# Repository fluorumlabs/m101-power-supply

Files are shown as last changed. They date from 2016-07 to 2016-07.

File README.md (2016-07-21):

# M101 Power Supply #

	Current version: M101 rev.D
	State: Tested
	Build Difficulty: Medium

Basic switched-mode power supply module for [FluorumLabs SonicTrain](https://github.com/fluorumlabs/sonictrain) modular sound processing system.

![Assembled Module]()

## Features ##

 * Up to 15W output power (500mA on positive and negative rails); depends on the DC-DC converter used.
 * 2.0 mm center pin DC power jack (center pin positive).
 * Reverse polarity protection.
 * Supports all ±15V dual output DC-DC converters in industry standard through-hole 1x1 footprint, with optional positive or negative remote ON/OFF control.
 * Optional ON/OFF switch.
 * Automatic optical switch provides power to the rest of the system only after the last (audio output) module is connected, guaranteeing the both rails will be powered simultaneously.
 * MOSFET current limiter for limiting in-rush current on system power-up.

![Plain PCB]()

![Populated PCB]()

## Schematics and PCB ##

 * [Schematics (PDF)](eagle/m101-power-supply.pdf)
 * [Schematics (Eagle 7)](eagle/m101-power-supply.sch)
 * [PCB (Eagle 7)](eagle/m101-power-supply.brd)

## Ordering and Building Notes ##

Populating the PCB should be relatively straightforward. Some notes:

 * Always check the correct orientation of components:
   * Diodes: square pad on PCB marks **anode**.
   * Electrolytic capacitors: square pad on PCB marks **positive** lead (the long lead).
   * IC, optocoupler: square pad on PCB marks **pin 1** of package.
   * LED: square pad on PCB marks **anode** of the **first diode** (the second longest lead).
   * MOSFET: square pads on PCB mark MOSFET **drain** (two connected pins).

 * The switch orientation depends on remote ON/OFF function of selected DC-DC converter:
   * Positive remote ON/OFF: mount switch in POS position.
   * Negative remove ON/OFF: mount switch in NEG position.

 * If you want to omit switch and selected DC-DC converter has a negative remote ON/OFF function, connect two solder pads beneath the switch on the bottom side of the board.

 * If selected DC-DC converter doesn't have remote ON/OFF feature, leave the switch out.

## Bill of Materials (Assembly M101 rev.D) ##

Qty | RefDes | Component | Notes
--- | ------ | --------- | -----
1 | PCB1 | PCB M101 rev.D |
2 | C1, C3 | Capacitors Aluminium 33u/50V 8x7mm | Low profile
1 | C2 | Capacitors Aluminium 10u/35V 5x7mm | Low profile
2 | C4, C7 | Capacitors Ceramic 100n Radial | Lead space 5mm
2 | C5, C6 | Capacitors Aluminium Organic 39u/35V 8x7mm | Low profile
2 | C8, C9 | Capacitors Film 100n 2.5x7.2x6mm
2 | C10, C11 | Capacitors Aluminium 1u/50V 4x7mm | Low profile
2 | C12, C13 | Capacitors Film 22n 2.5x7.2x6mm
1 | DA1 | IC Logic NE555 DIP-8 |
1 | HL1 | LED 2x5x7mm Diffused Red/Blue (Common Cathode) |
1 | L1 | Ferrite Bead Axial |
1 | R1 | Resistors 22k 1% 0.25W |
1 | R2 | Resistors Array 4x100k SIP-5 |
1 | R3 | Resistors 10k 1% 0.25W |
3 | R4, R6, R7 | Resistors 100k 1% 0.25W |
3 | R5, R8, R9 | Resistors 1k5 1% 0.25W |
2 | R10, R11 | Resistors 220k 1% 0.125W |
2 | R12, R13 | Resistors 100R 1% 0.25W |
1 | SA1 | Switches Slide MHS122K | Optional, leave out if no switch is needed
2 | U1, U2 | Hardware Screw M2x8 Hex | For Hirose FX2 connector
2 | U3, U4 | Hardware Nut M2 Self-locking | For Hirose FX2 connector
1 | U5 | Connectors Hirose FX2-20P-1.27DS |
1 | U6 | DC/DC Converter SHHN000A3CL41Z 9W C1 | ±15V dual output DC-DC converters in industry standard through-hole 1x1 footprint
1 | U7 | Optocoupler G3VM-62C1 DIP-8 |
1 | U8 | Hardware ERM1-5MM | 5mm LED standoff for HL1
3 | VD1, VD3, VD4 | Diodes Zener 1N4740 10V DO-41 | Standard 10V zener diode
1 | VD2 | Diodes BAT46 DO-35 | Standard small signal diode will also work (1N4148 etc.)
_1_ | _VT1_ | _Transistors MOSFET IRFD014 HVMDIP-4_ | _Populate only if input current is expected to be greater than 1.5A_
2 | VT2, VT4 | Transistors MOSFET IRFD014 HVMDIP-4 |
1 | VT3 | Transistors MOSFET IRFD9024 HVMDIP-4 |
1 | XS1 | Connectors CUI PJ-051AH 2.0mm |

## Bill of Materials (M101 Power Supply) ##

Qty |  Component | Notes
--- |  --------- | -----
1 |   Assembly M101 rev.D |
1 |   [Hardware ZZ050 Bottom](dxf/zz050.dxf) |
1 |   [Hardware ZM101 Top](dxf/zm101.dxf) | Low profile DC-DC and switch
_1_ |   _[Hardware ZM101-NO-SWITCH Top](dxf/zm101-no-switch.dxf)_ | _Low profile DC-DC and no switch_
_1_ |   _[Hardware ZM101-HP Top](dxf/zm101-hp.dxf)_ | _Normal DC-DC and switch_
_1_ |   _[Hardware ZM101-HP-NO-SWITCH Top](dxf/zm101-hp-no-switch.dxf)_ | _Normal DC-DC and no switch_
8 |   Hardware Screw M2x8 Hex |
8 |   Hardware Screw M2x10 Hex |
8 |   Hardware Standoff M2x3 |
8 |   Hardware Standoff M2x9 |
180mm |   Hardware Magnetic Tape 12x1.5mm | 2 x 9cm

## Legal ##

Designed by Artem Godin.

Licensed under the terms of [CERN Open Hardware Licence v1.2](LICENSE)

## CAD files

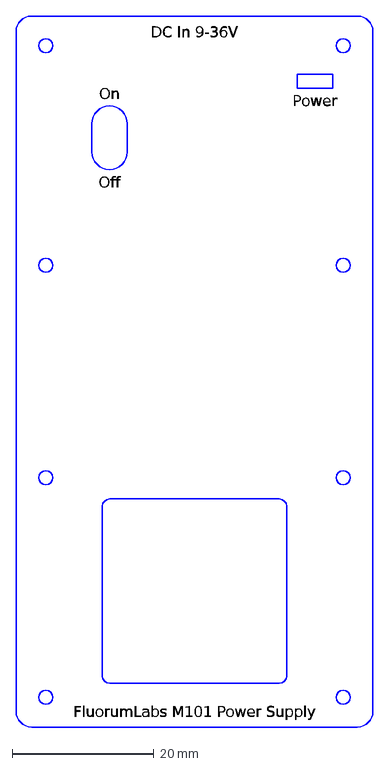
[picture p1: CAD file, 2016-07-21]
dxf/zm101-hp.dxf
Power
FluorumLabs M101 Power Supply
DC In 9-36V
On
Off

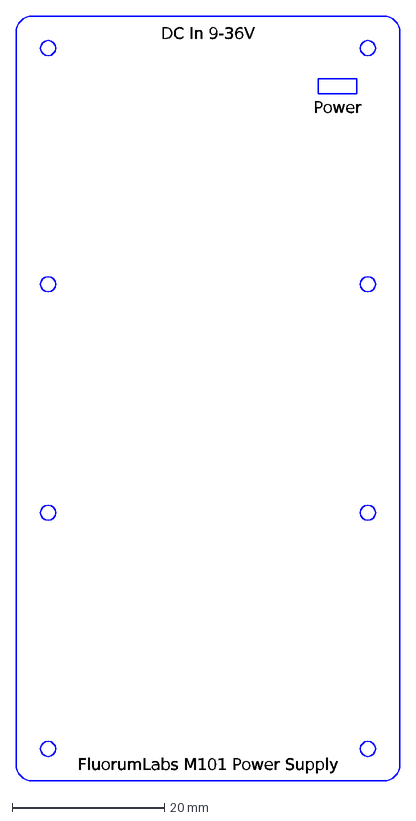
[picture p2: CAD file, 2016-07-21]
dxf/zm101-no-switch.dxf
Power
FluorumLabs M101 Power Supply
DC In 9-36V

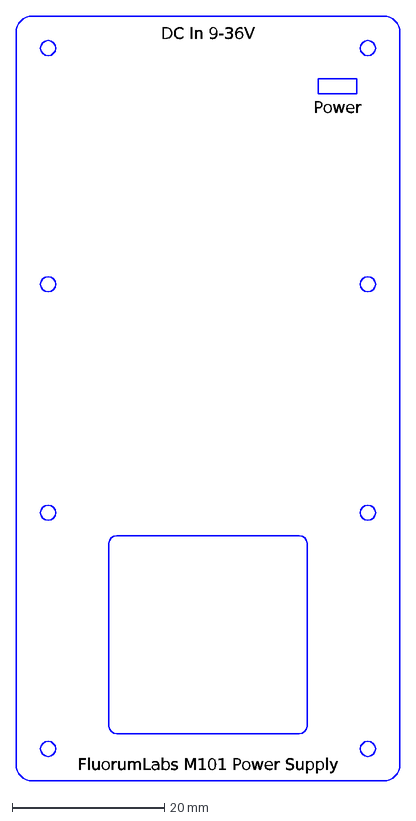
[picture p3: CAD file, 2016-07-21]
dxf/zm101-hp-no-switch.dxf
Power
FluorumLabs M101 Power Supply
DC In 9-36V

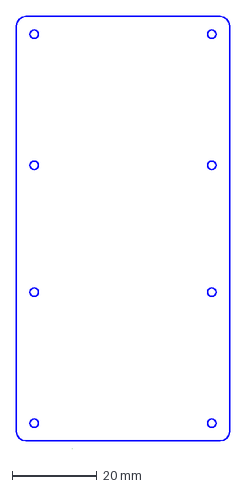
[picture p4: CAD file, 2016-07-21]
dxf/zz050.dxf
50.4 x 102.2 mm

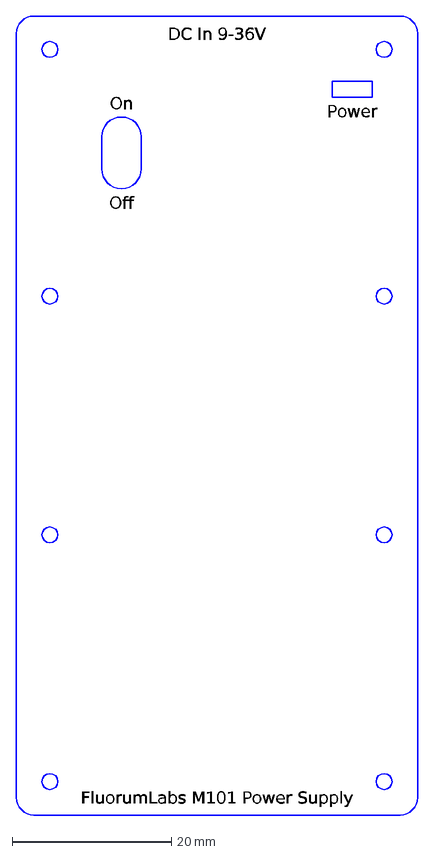
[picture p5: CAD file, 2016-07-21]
dxf/zm101.dxf
Power
FluorumLabs M101 Power Supply
DC In 9-36V
On
Off

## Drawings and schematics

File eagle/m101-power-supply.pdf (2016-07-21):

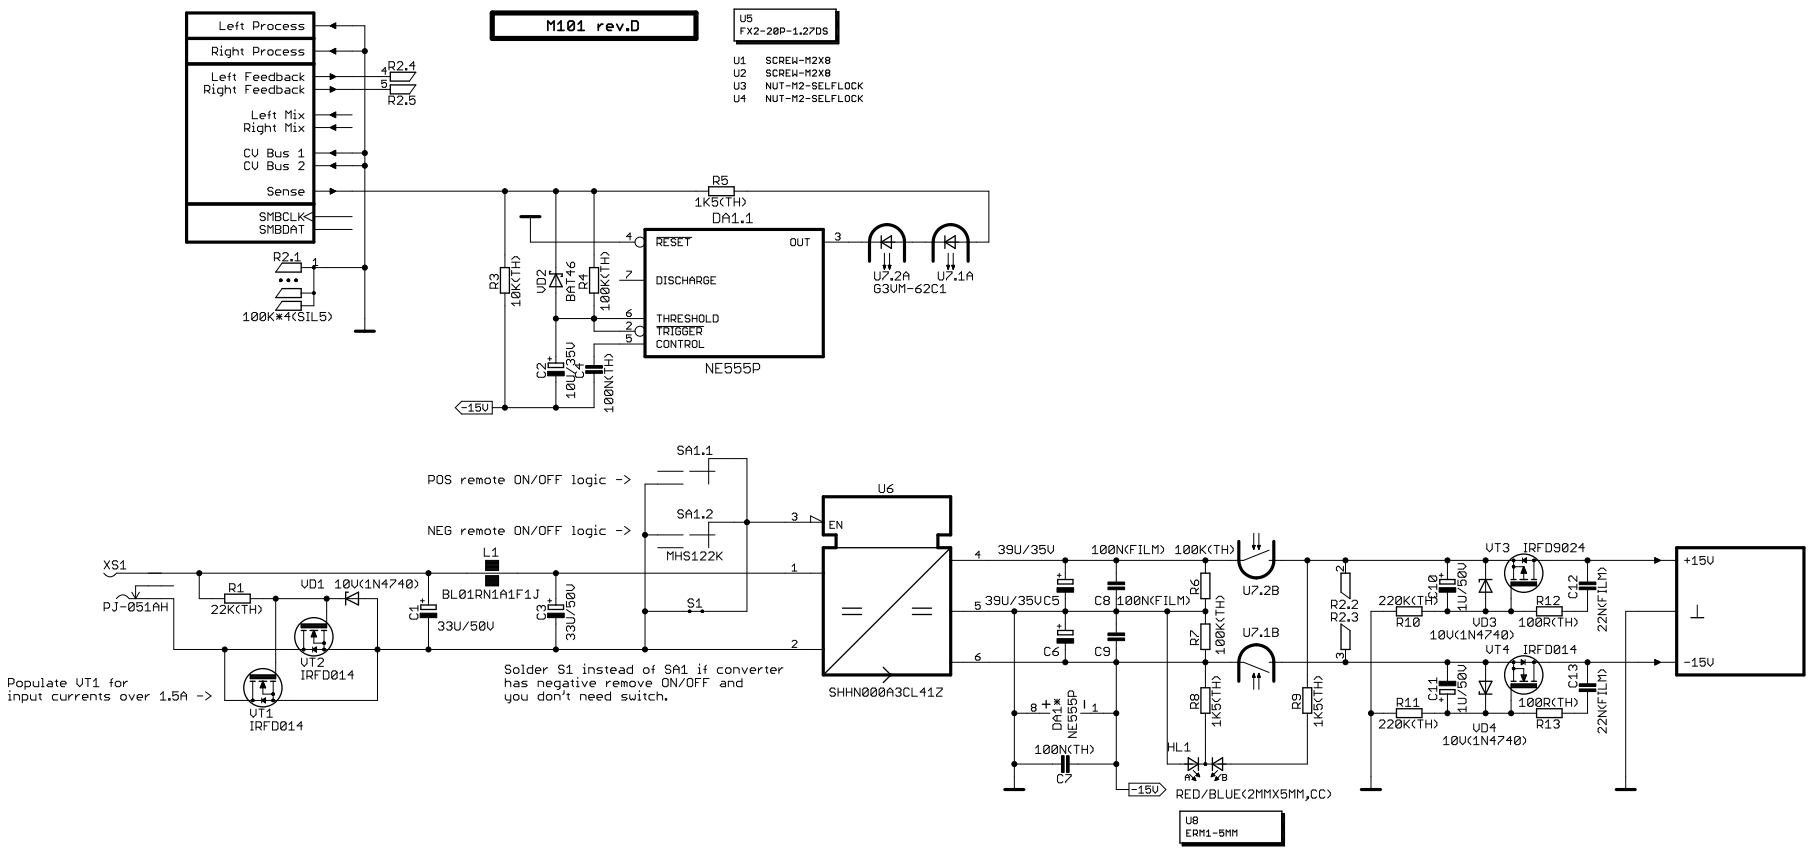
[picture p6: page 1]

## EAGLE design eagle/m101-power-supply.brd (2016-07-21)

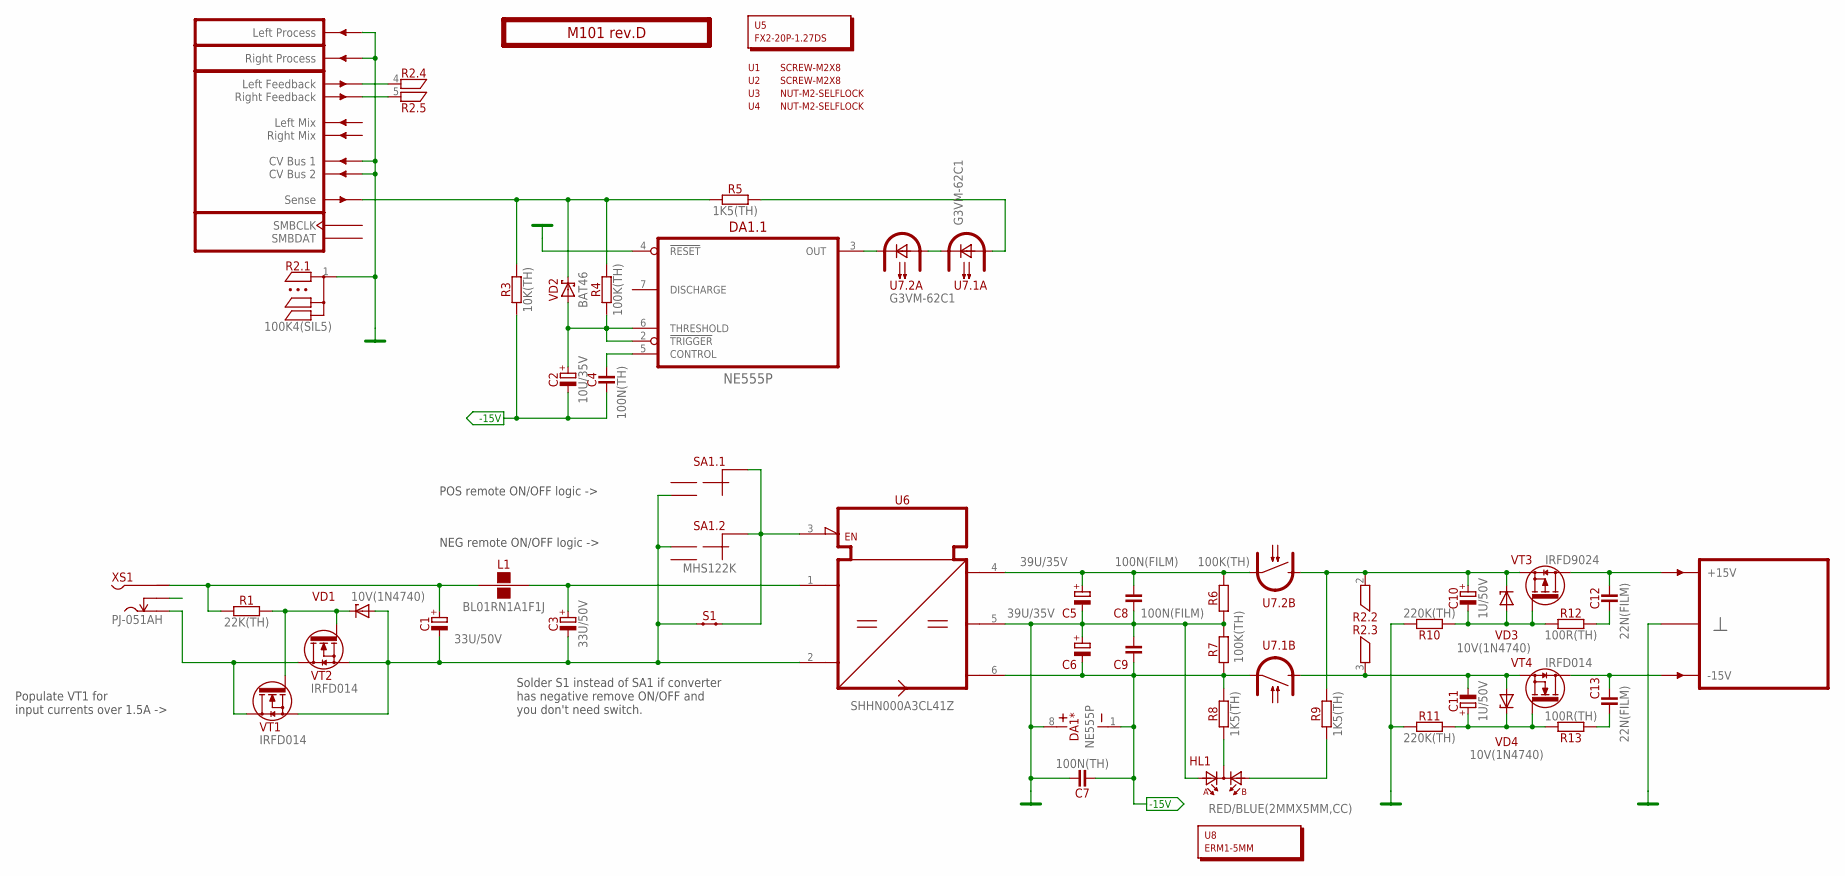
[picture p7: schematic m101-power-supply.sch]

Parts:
C1, C3: 33U/50V; E3,5-8
C2: 10U/35V; E2-5
C4, C7: 100N(TH); C050-024X044
C5, C6: 39U/35V; E3,5-8
C8, C9: 100N(FILM); C050-025X075
C10, C11: 1U/50V; E1,5-4
C12, C13: 22N(FILM); C050-025X075
DA1: NE555P; DIP-8
HL1: RED/BLUE(2MMX5MM,CC); LED2X5-3PIN
L1: BL01RN1A1F1J; BL01RN1A
PCB1: M101 rev.D; ST2-BOARD-50-PSU
R1: 22K(TH); R-0207/10
R2: 100K4(SIL5); R-SIL5
R3: 10K(TH); R-0207/10
R4, R6, R7: 100K(TH); R-0207/10
R5, R8, R9: 1K5(TH); R-0207/10
R10, R11: 220K(TH); R-0207/10
R12, R13: 100R(TH); R-0207/10
S1: JUMPER-1POS-SOLDER; JP1-SOLDER
SA1: MHS122K; APEM-MHS122K
U1, U2: SCREW-M2X8; EMPTY
U3, U4: NUT-M2-SELFLOCK; EMPTY
U5: FX2-20P-1.27DS; EMPTY
U6: SHHN000A3CL41Z; DC/DC-C1
U7: G3VM-62C1; DIL08
U8: ERM1-5MM; EMPTY
VD1, VD3, VD4: 10V(1N4740); DO41-10
VD2: BAT46; DO35-7
VT1, VT2, VT4: IRFD014; HVMDIP-4
VT3: IRFD9024; HVMDIP-4
XS1: PJ-051AH

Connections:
-15V: C2.-, C4.1, C6.-, C7.1, C9.1, DA1.1 (V-), R3.1, R7.1, R8.2, U6.6 (V-), U7.7 (S2)
GND: C5.-, C6.+, C7.2, C8.1, C9.2, DA1.4 (!RESET), DA1.8 (V+), HL1.A1, PCB1.ACV1' (CV1'), PCB1.ACV2' (CV2'), PCB1.B4' (GND), PCB1.B5' (GND), PCB1.B6' (GND), PCB1.B7' (GND), PCB1.B8' (GND), PCB1.BOUTL' (OUTL), PCB1.BOUTR' (OUTR), R2.1, R6.1, R7.2, R10.2, R11.2, U6.5 (GND)
unnamed: R5.2, U7.1 (A)
unnamed: C1.-, C3.-, S1.1, SA1.1' (1), SA1.2, U6.2 (IN-), VD1.A, VT1.4 (S), VT2.4 (S)
unnamed: PCB1.ALFBK' (LFBK'), R2.4
unnamed: PCB1.ARFBK' (RFBK'), R2.5
unnamed: C4.2, DA1.5 (CONTROL)
unnamed: DA1.3 (OUT), U7.4 (C)
unnamed: VT1.1 (D), VT1.2 (D), VT2.1 (D), VT2.2 (D), XS1.3 (S)
unnamed: U7.2 (C), U7.3 (A)
unnamed: C2.+, DA1.2 (!TRIGGER), DA1.6 (THRESHOLD), R4.1, VD2.A
unnamed: C10.+, R2.2, R9.2, U7.6 (S1), VD3.C, VT3.4 (S)
unnamed: R1.2, VD1.C, VT1.3 (G), VT2.3 (G)
unnamed: HL1.K, R8.1
unnamed: HL1.A2, R9.1
unnamed: C5.+, C8.2, R6.2, U6.4 (V+), U7.5 (S2)
unnamed: S1.2, SA1.CMN (CM), SA1.CMN' (CM), U6.3 (EN)
unnamed: C10.-, R10.1, R12.1, VD3.A, VT3.3 (G)
unnamed: C12.2, PCB1.A+15' (P+15V), PCB1.B+15' (P+15V), VT3.1 (D), VT3.2 (D)
unnamed: C12.1, R12.2
unnamed: C1.+, L1.1, R1.1, XS1.1
unnamed: C13.1, PCB1.A-15' (P-15V), PCB1.B-15' (P-15V), VT4.1 (D), VT4.2 (D)
unnamed: C3.+, L1.2, U6.1 (IN+)
unnamed: C13.2, R13.2
unnamed: C11.+, R11.1, R13.1, VD4.C, VT4.3 (G)
unnamed: C11.-, R2.3, U7.8 (S1), VD4.A, VT4.4 (S)
SENSE: PCB1.BSENSE' (SENSE'), R3.2, R4.2, R5.1, VD2.C

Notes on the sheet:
Populate VT1 for input currents over 1.5A ->
POS remote ON/OFF logic ->
NEG remote ON/OFF logic ->
Solder S1 instead of SA1 if converter has negative remove ON/OFF and you don't need switch.

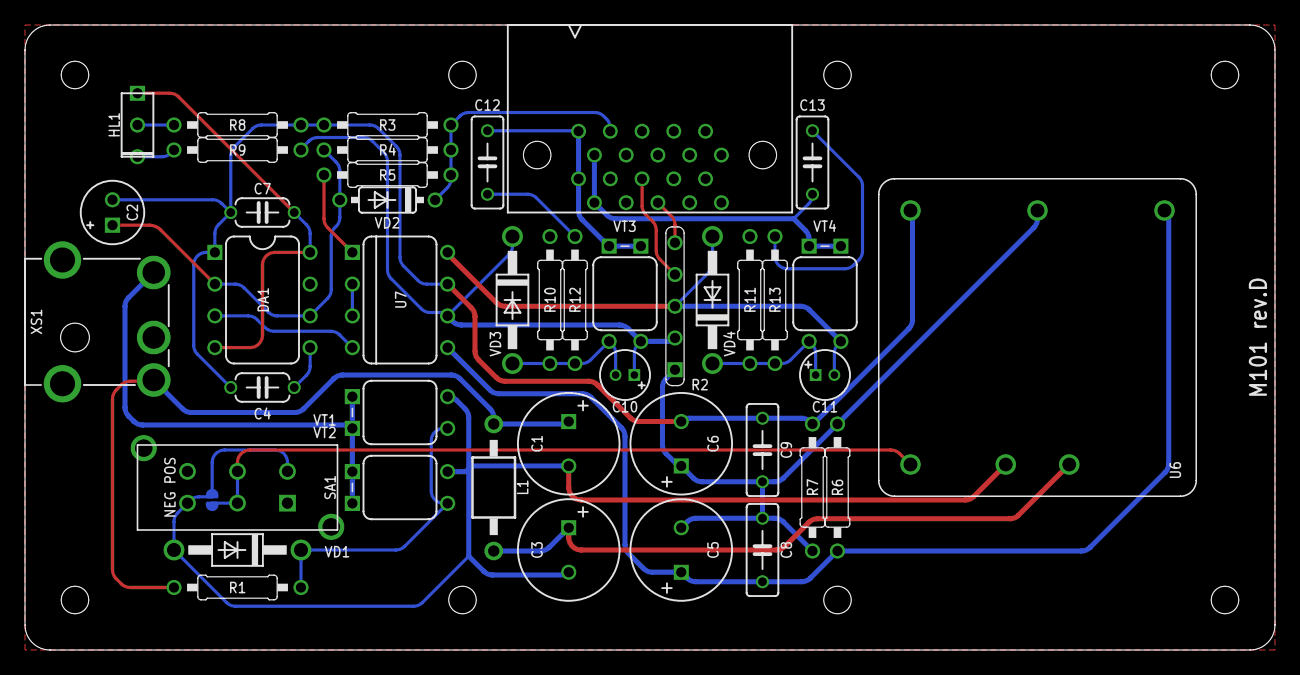
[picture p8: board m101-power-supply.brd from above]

Board: 2 copper layers, 100.0 x 50.0 mm, 49 parts (1 on the bottom side), 27 nets.

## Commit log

2016-07-21 Documentation WIP
    [m101-power-supply.brd, m101-power-supply.sch, zm101-hp-no-switch.dxf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]
2016-07-21 Documentation update
    [m101-power-supply.sch]
